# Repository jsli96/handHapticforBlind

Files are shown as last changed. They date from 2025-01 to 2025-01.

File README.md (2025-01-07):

# Hand Haptic for Blind Users in VR
This repo is for paper "Comparing Vibrotactile and Skin-Stretch Haptic Feedback for Conveying
Spatial Information of Virtual Objects to Blind VR Users"

The repo includes the list of hardware (3D model), control interface, Arduion code for motors, and calibration & test applications.

The image of testing device

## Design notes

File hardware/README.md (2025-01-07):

# Hardware componment list

1. linear rail with motor:
	- x axis (x1): https://a.co/d/0Zzcw9q
	- y axis (x2): https://a.co/d/i22Iq13
	- z axis (x1): https://a.co/d/0KRT372

2. T Slot Aluminum Linear Rail:
	- link: https://a.co/d/4vl8tA6
	- used for base frame and linkage 
3. Axis stand:
	- Use axis stand to connect T-slot Aluminum and two y axes linear rails.
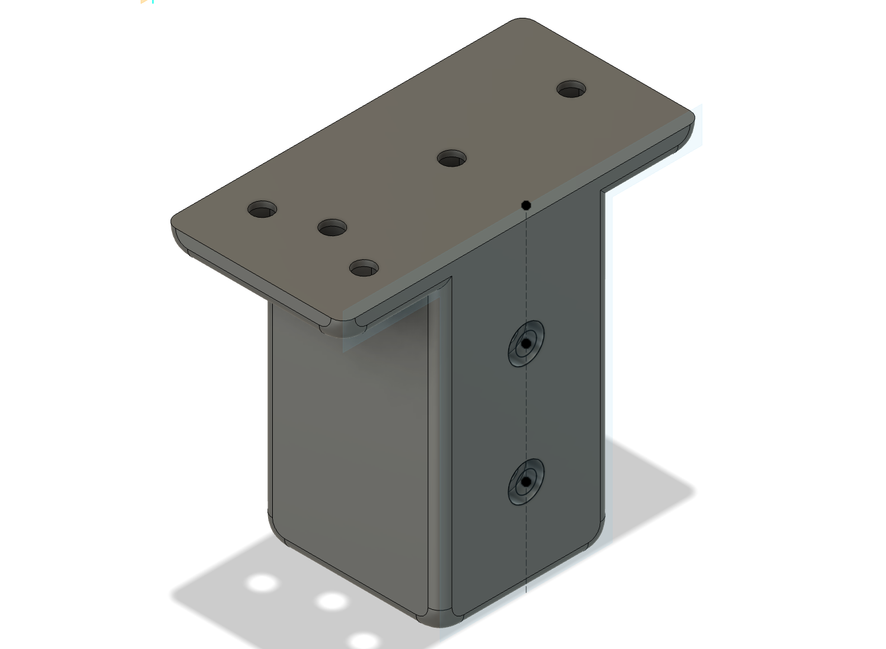
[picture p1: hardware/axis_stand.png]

4. Axis connector:
	- Use axis connector to connect x and z axis linear rail.
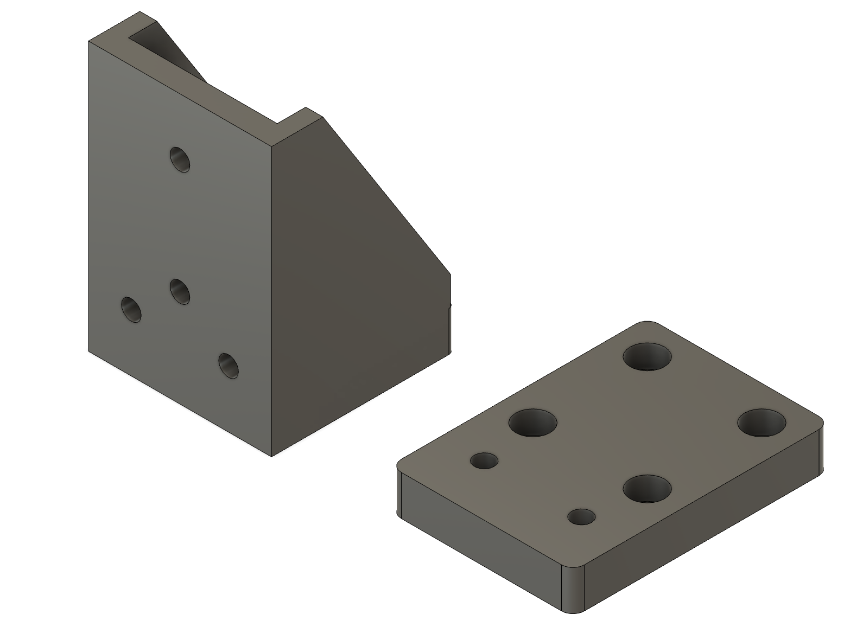
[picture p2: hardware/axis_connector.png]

5. Z probe linkage:
	- Attach Z probe linkage on the axis connector:
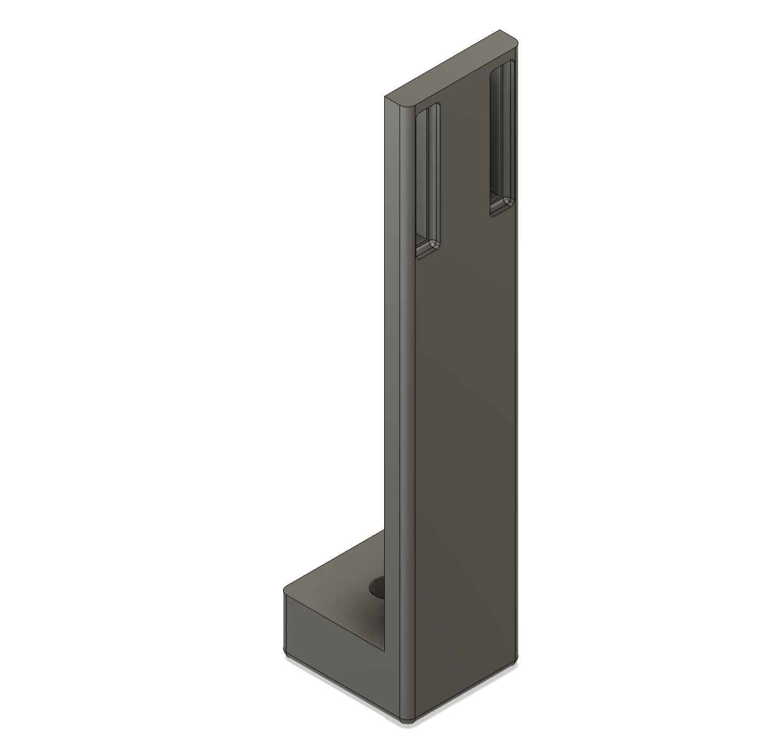
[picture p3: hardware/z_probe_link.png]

6. hand support:
	- Printed out one of these to rest users hand during the test.
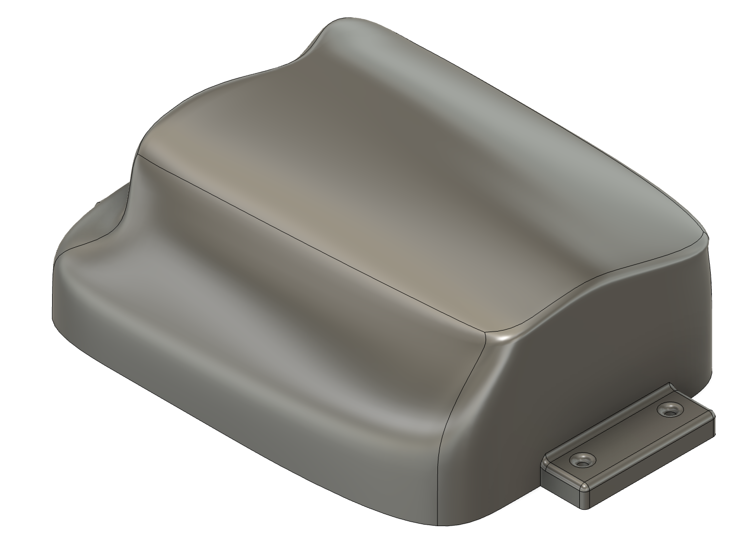
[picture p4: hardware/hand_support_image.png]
The image of testing device


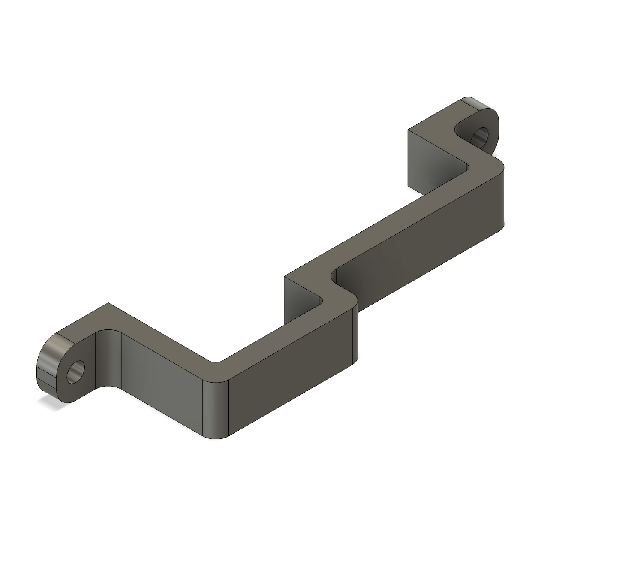
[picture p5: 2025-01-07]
hardware/camera_mount.png

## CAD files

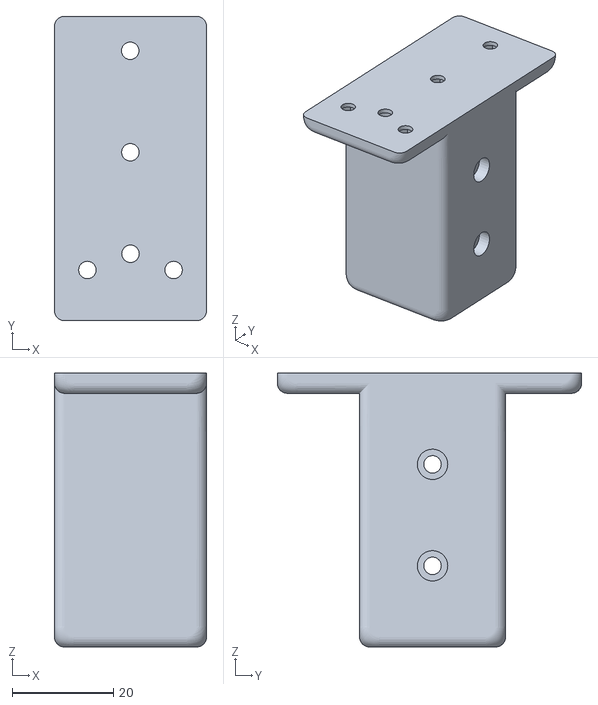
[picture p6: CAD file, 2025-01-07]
hardware/axis_stand.stl
30.0 x 60.0 x 54.0

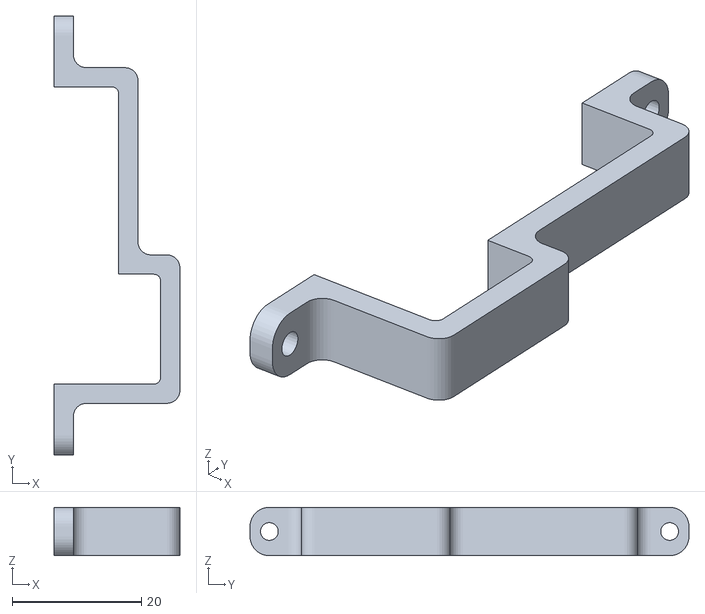
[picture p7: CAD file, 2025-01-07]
hardware/camera_mount.stl
19.5 x 68.0 x 7.50

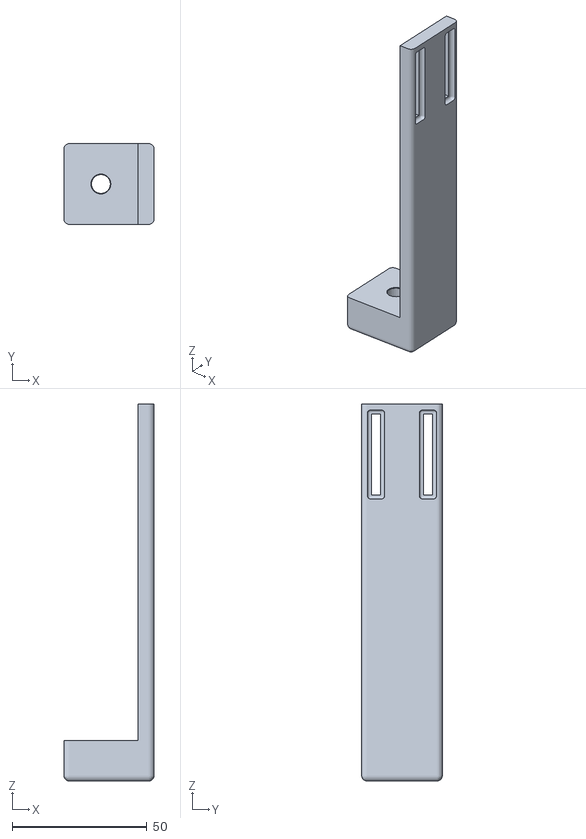
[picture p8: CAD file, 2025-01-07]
hardware/z_probe_link.stl
33.5 x 30.0 x 140.0

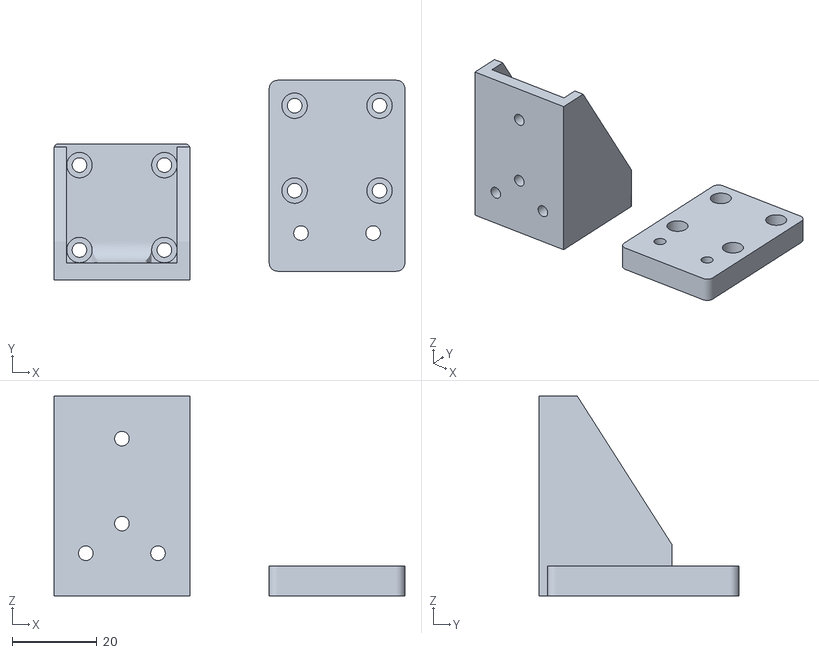
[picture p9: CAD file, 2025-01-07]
hardware/axis_connector.stl
82.7 x 47.0 x 47.0

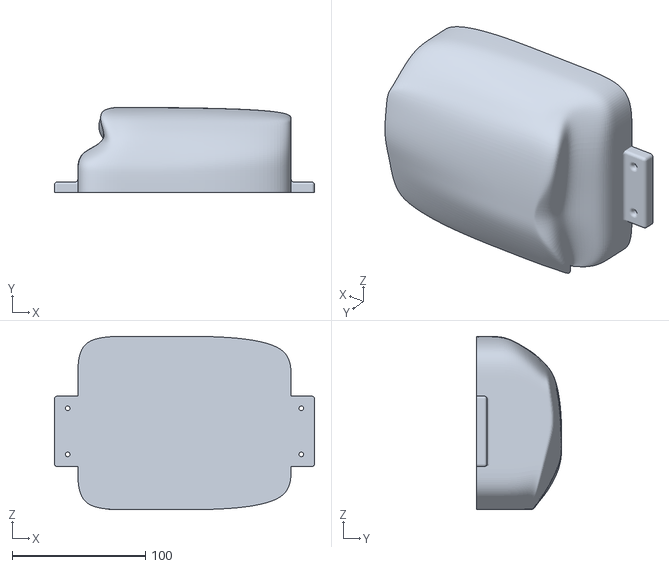
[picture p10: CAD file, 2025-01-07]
hardware/hand support.stl
194.9 x 64.0 x 130.0

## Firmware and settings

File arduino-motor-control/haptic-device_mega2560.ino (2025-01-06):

#include <TimerOne.h>
#include <AccelStepper.h>
#include <elapsedMillis.h>
#define y_Enable 56
#define y_Step 60
#define y_Dir 61
#define y_Stop 3
#define x_Enable 38
#define x_Step 54
#define x_Dir 55
#define x_Stop 2
#define z_Enable 62
#define z_Step 46
#define z_Dir 48
#define z_Stop 19
#define vib_motor_1 16

bool x_home = false;
bool y_home = false;
bool z_home = false;
const long x_center_point = -12000;
const long y_center_point = -12000;
const long z_center_point = -1000;
const int full_distance = 5000;
const int half_distance = 2250;
const int full_distance_at_45 = 3535;
const int half_distance_at_45 = 1590;
long adj_x_center = -12000;
long adj_y_center = -12000;
long adj_z_center = -1000;
long adj_z_center_low = -1000;
long adj_z_left_low = -1000;
long adj_z_right_low = -1000;
long adj_z_front_low = -1000;
long adj_z_back_low = -1000;
long z_center_move_distance = 0;
long z_left_move_distance = 0;
long z_right_move_distance = 0;
long z_front_move_distance = 0;
long z_back_move_distance = 0;
boolean z_calibration = false;
boolean vib_mode = false;
boolean stretch_mode = false;
String incomingString = "0";

AccelStepper myStepper_x(AccelStepper::DRIVER, x_Step, x_Dir, true);
AccelStepper myStepper_y(AccelStepper::DRIVER, y_Step, y_Dir, true);
AccelStepper myStepper_z(AccelStepper::DRIVER, z_Step, z_Dir, true);
elapsedMillis printTime;

void pin_init()
{
  pinMode(y_Enable, OUTPUT);
  digitalWrite(y_Enable, LOW); // the motor enable pin needs to be LOW to make driver works
  pinMode(x_Enable, OUTPUT);
  digitalWrite(x_Enable, LOW); // the motor enable pin needs to be LOW to make driver works
  pinMode(z_Enable, OUTPUT);
  digitalWrite(z_Enable, LOW); // the motor enable pin needs to be LOW to make driver works
  pinMode(x_Stop, INPUT_PULLUP);
  attachInterrupt(digitalPinToInterrupt(x_Stop), x_intr, FALLING); // Stop pin interrupt
  pinMode(y_Stop, INPUT_PULLUP);
  attachInterrupt(digitalPinToInterrupt(y_Stop), y_intr, FALLING); // Stop pin interrupt
  pinMode(z_Stop, INPUT_PULLUP);
  attachInterrupt(digitalPinToInterrupt(z_Stop), z_intr, FALLING); // Stop pin interrupt
  pinMode(vib_motor_1, OUTPUT);
  digitalWrite(vib_motor_1, LOW);
  // Initial the motor and return to the zero.
  initial_to_zero(); // Find the zero position.
}

void x_intr()
{
  static unsigned long last_interrupt_time = 0;
  unsigned long interrupt_time = millis();
  if (interrupt_time - last_interrupt_time > 900)
  {
    myStepper_x.setSpeed(0);
    x_home = true;
    Serial.println("X Motor speed set to zero.");
  }
  last_interrupt_time = interrupt_time;
}

void y_intr()
{
  static unsigned long last_interrupt_time = 0;
  unsigned long interrupt_time = millis();
  if (interrupt_time - last_interrupt_time > 900)
  {
    myStepper_y.setSpeed(0);
    y_home = true;
    Serial.println("Y Motor speed set to zero.");
  }
  last_interrupt_time = interrupt_time;
}

void z_intr()
{
  static unsigned long last_interrupt_time = 0;
  unsigned long interrupt_time = millis();
  if (interrupt_time - last_interrupt_time > 600)
  {
    myStepper_z.setSpeed(0);
    z_home = true;
    Serial.println("Z Motor speed set to zero.");
  }
  last_interrupt_time = interrupt_time;
}

void setup()
{
  Serial.begin(115200);
  myStepper_x.setMaxSpeed(1500.0); // the motor accelerates to this speed exactly without overshoot.
  myStepper_y.setMaxSpeed(1500.0); // the motor accelerates to this speed exactly without overshoot.
  myStepper_z.setMaxSpeed(1500.0); // the motor accelerates to this speed exactly without overshoot.
  myStepper_x.setAcceleration(100);
  myStepper_y.setAcceleration(100);
  myStepper_z.setAcceleration(100);
  pin_init(); // Initial the pin output functionalities.
  delay(1000);
  Serial.println("Begin moving to the center point.");
  move_to_center(x_center_point, y_center_point, z_center_point); // Move to the pre-set center point.
  detachInterrupt(digitalPinToInterrupt(x_Stop));
  detachInterrupt(digitalPinToInterrupt(y_Stop));
  detachInterrupt(digitalPinToInterrupt(z_Stop));
  Serial.println("System ready!!!");
}

void loop()
{
  if (Serial.available())
  {
    incomingString = Serial.readString();
    if (incomingString == "stop motors")
    {
      digitalWrite(y_Enable, HIGH);
      digitalWrite(x_Enable, HIGH);
      digitalWrite(z_Enable, HIGH);
      Serial.println("All motors are shutted down!");
    }
    else if (incomingString == "start motors")
    {
      digitalWrite(y_Enable, LOW);
      digitalWrite(x_Enable, LOW);
      digitalWrite(z_Enable, LOW);
      Serial.println("Motors started!");
    }
    else if (incomingString == "log xyz")
    {
      log_adjust_center_point();
    }
    else if (incomingString == "log center z lowest point")
    {
      log_center_z_lowest_point();
    }
    else if (incomingString == "log left z lowest point")
    {
      log_left_z_lowest_point();
    }
    else if (incomingString == "log right z lowest point")
    {
      log_right_z_lowest_point();
    }
    else if (incomingString == "log front z lowest point")
    {
      log_front_z_lowest_point();
    }
    else if (incomingString == "log back z lowest point")
    {
      log_back_z_lowest_point();
    }
    else if (incomingString == "pre-set home")
    {
      move_to_center(x_center_point, y_center_point, z_center_point);
    }
    else if (incomingString == "adjusted home")
    {
      move_to_center(adj_x_center, adj_y_center, adj_z_center);
    }
    else if (incomingString == "show current location")
    {
      show_current_location();
    }
    else if (incomingString[0] == 'x' || incomingString[0] == 'y' || incomingString[0] == 'z')
    {
      adjust_probe_position(incomingString);
    }
    else
    {
      points_select(incomingString);
    }

    Serial.println("Standby...");
  }
  delay(500);
}

void initial_to_zero()
{
  myStepper_y.setSpeed(1250); // Positive speed will move to zero point, negative point will move to oppisite direction.
  myStepper_x.setSpeed(1250);
  myStepper_z.setSpeed(1250);
  while (x_home == false || y_home == false || z_home == false)
  {
    myStepper_y.runSpeed();
    myStepper_x.runSpeed();
    myStepper_z.runSpeed();
  }
  myStepper_x.setCurrentPosition(0);
  myStepper_y.setCurrentPosition(0);
  myStepper_z.setCurrentPosition(0);
  myStepper_x.stop();
  myStepper_y.stop();
  myStepper_z.stop();
  Serial.println("Motor at zero position.");
}

void move_to_center(long x_c, long y_c, long z_c)
{
  myStepper_x.moveTo(x_c);
  myStepper_y.moveTo(y_c);
  myStepper_z.moveTo(z_c);
  while (myStepper_x.distanceToGo() != 0 || myStepper_y.distanceToGo() != 0 || myStepper_z.distanceToGo() != 0)
  {
    myStepper_x.setSpeed(cal_speed_dir(x_c, myStepper_x.currentPosition(), 1400));
    myStepper_y.setSpeed(cal_speed_dir(y_c, myStepper_y.currentPosition(), 1400));
    myStepper_z.setSpeed(cal_speed_dir(z_c, myStepper_z.currentPosition(), 1400));
    if (myStepper_x.distanceToGo() != 0)
    {
      myStepper_x.run();
    }
    if (myStepper_y.distanceToGo() != 0)
    {
      myStepper_y.run();
    }
    if (myStepper_z.distanceToGo() != 0)
    {
      myStepper_z.run();
    }
  }
  Serial.println("Probe at the center position.");
  show_current_location();
}

void show_current_location()
{
  Serial.print("Current motor poistion (x, y, z): ");
  Serial.print(myStepper_x.currentPosition());
  Serial.print(", ");
  Serial.print(myStepper_y.currentPosition());
  Serial.print(", ");
  Serial.println(myStepper_z.currentPosition());
}

void adjust_probe_position(String incomingString)
{
  switch (incomingString[0])
  {
  case 'x':
    Serial.print("Axis: ");
    Serial.println(incomingString[0]);
    Serial.print("Destination: ");
    Serial.println(incomingString.substring(2).toInt());
    move_x(incomingString.substring(2).toInt(), 1400);
    break;
  case 'y':
    Serial.print("Axis: ");
    Serial.println(incomingString[0]);
    Serial.print("Destination: ");
    Serial.println(incomingString.substring(2).toInt());
    move_y(incomingString.substring(2).toInt(), 1400);
    break;
  case 'z':
    Serial.print("Axis: ");
    Serial.println(incomingString[0]);
    Serial.print("Destination: ");
    Serial.println(incomingString.substring(2).toInt());
    move_z(incomingString.substring(2).toInt(), 1400);
    break;
  }
}

void points_select(String incomingString)
{
  Serial.println(incomingString);
  if (adj_x_center == -12000 || adj_y_center == -12000)
  {
    Serial.println("Please calbiate and log x y z postion first!");
  }
  if (z_calibration == false)
  {
    Serial.println("Please calbiate the lowest z postion first!");
  }
  if (z_calibration == true && adj_x_center != -12000 && adj_y_center != -12000)
  {
    int temp = incomingString.toInt();
    Serial.print("Incoming point: ");
    Serial.println(temp);
    switch (temp)
    {
    case 16:
      point_16();
      break;
    case 15:
      point_15();
      break;
    case 14:
      point_14();
      break;
    case 13:
      point_13();
      break;
    case 12:
      point_12();
      break;
    case 11:
      point_11();
      break;
    case 10:
      point_10();
      break;
    case 9:
      point_9();
      break;
    case 8:
      point_8();
      break;
    case 7:
      point_7();
      break;
    case 6:
      point_6();
      break;
    case 5:
      point_5();
      break;
    case 4:
      point_4();
      break;
    case 3:
      point_3();
      break;
    case 2:
      point_2();
      break;
    case 1:
      point_1();
      break;
    case 21:
      h_left();
      break;
    case 22:
      h_right();
      break;
    case 23:
      v_backward();
      break;
    case 24:
      v_forward();
      break;
    case 25:
      multi_fb();
      break;
    case 26:
      multi_incomplete_t();
      break;
    case 27:
      multi_complete_t();
      break;
    case 28:
      big_left_curve();
      break;
    case 29:
      small_right_curve();
      break;
    case 30:
      s_curve();
      break;

      //======================================================================//
    case 46:
      point_16_vib();
      break;
    case 45:
      point_15_vib();
      break;
    case 44:
      point_14_vib();
      break;
    case 43:
      point_13_vib();
      break;
    case 42:
      point_12_vib();
      break;
    case 41:
      point_11_vib();
      break;
    case 40:
      point_10_vib();
      break;
    case 39:
      point_9_vib();
      break;
    case 38:
      point_8_vib();
      break;
    case 37:
      point_7_vib();
      break;
    case 36:
      point_6_vib();
      break;
    case 35:
      point_5_vib();
      break;
    case 34:
      point_4_vib();
      break;
    case 33:
      point_3_vib();
      break;
    case 32:
      point_2_vib();
      break;
    case 31:
      point_1_vib();
      break;
    case 51:
      h_left_vib();
      break;
    case 52:
      h_right_vib();
      break;
    case 53:
      v_backward_vib();
      break;
    case 54:
      v_forward_vib();
      break;
    case 55:
      multi_fb_vib();
      break;
    case 56:
      multi_incomplete_t_vib();
      break;
    case 57:
      multi_complete_t_vib();
      break;
    case 58:
      big_left_curve_vib();
      break;
    case 59:
      small_right_curve_vib();
      break;
    case 60:
      s_curve_vib();
      break;
      //======================================================================//

    default:
      Serial.println("Commands not match!");
      break;
    }
  }
}

void log_adjust_center_point()
{
  adj_x_center = myStepper_x.currentPosition();
  adj_y_center = myStepper_y.currentPosition();
  adj_z_center = myStepper_z.currentPosition();
  Serial.println("Adjust center point logged!");
  show_current_location();
}

void log_center_z_lowest_point()
{
  adj_z_center_low = myStepper_z.currentPosition();
  z_center_move_distance = adj_z_center_low - adj_z_center;
  Serial.println("Z axis center lowest point logged!");
  Serial.print("Z axis center movement distance is ");
  Serial.println(z_center_move_distance);
  Serial.print(z_center_move_distance);
  Serial.print(',');
  Serial.print(z_left_move_distance);
  Serial.print(',');
  Serial.print(z_right_move_distance);
  Serial.print(',');
  Serial.print(z_front_move_distance);
  Serial.print(',');
  Serial.println(z_back_move_distance);

  show_current_location();
  if (z_center_move_distance == 0 || z_left_move_distance == 0 || z_right_move_distance == 0 || z_front_move_distance == 0 || z_back_move_distance == 0)
  {
    z_calibration = false;
  }
  else
  {
    z_calibration = true;
  }
}

void log_left_z_lowest_point()
{
  adj_z_left_low = myStepper_z.currentPosition();
  z_left_move_distance = adj_z_left_low - adj_z_center;
  Serial.println("Z axis left center lowest point logged!");
  Serial.print("Z axis left center movement distance is ");
  Serial.println(z_left_move_distance);
  Serial.print(z_center_move_distance);
  Serial.print(',');
  Serial.print(z_left_move_distance);
  Serial.print(',');
  Serial.print(z_right_move_distance);
  Serial.print(',');
  Serial.print(z_front_move_distance);
  Serial.print(',');
  Serial.println(z_back_move_distance);
  show_current_location();
  if (z_center_move_distance == 0 || z_left_move_distance == 0 || z_right_move_distance == 0 || z_front_move_distance == 0 || z_back_move_distance == 0)
  {
    z_calibration = false;
  }
  else
  {
    z_calibration = true;
  }
}

void log_right_z_lowest_point()
{
  adj_z_right_low = myStepper_z.currentPosition();
  z_right_move_distance = adj_z_right_low - adj_z_center;
  Serial.println("Z axis right lowest point logged!");
  Serial.print("Z axis right movement distance is ");
  Serial.println(z_right_move_distance);
  Serial.print(z_center_move_distance);
  Serial.print(',');
  Serial.print(z_left_move_distance);
  Serial.print(',');
  Serial.print(z_right_move_distance);
  Serial.print(',');
  Serial.print(z_front_move_distance);
  Serial.print(',');
  Serial.println(z_back_move_distance);
  show_current_location();
  if (z_center_move_distance == 0 || z_left_move_distance == 0 || z_right_move_distance == 0 || z_front_move_distance == 0 || z_back_move_distance == 0)
  {
    z_calibration = false;
  }
  else
  {
    z_calibration = true;
  }
}

void log_front_z_lowest_point()
{
  adj_z_front_low = myStepper_z.currentPosition();
  z_front_move_distance = adj_z_front_low - adj_z_center;
  Serial.println("Z axis front lowest point logged!");
  Serial.print("Z axis front movement distance is ");
  Serial.println(z_front_move_distance);
  Serial.print(z_center_move_distance);
  Serial.print(',');
  Serial.print(z_left_move_distance);
  Serial.print(',');
  Serial.print(z_right_move_distance);
  Serial.print(',');
  Serial.print(z_front_move_distance);
  Serial.print(',');
  Serial.println(z_back_move_distance);
  show_current_location();
  if (z_center_move_distance == 0 || z_left_move_distance == 0 || z_right_move_distance == 0 || z_front_move_distance == 0 || z_back_move_distance == 0)
  {
    z_calibration = false;
  }
  else
  {
    z_calibration = true;
  }
}

void log_back_z_lowest_point()
{
  adj_z_back_low = myStepper_z.currentPosition();
  z_back_move_distance = adj_z_back_low - adj_z_center;
  Serial.println("Z axis back lowest point logged!");
  Serial.print("Z axis back movement distance is ");
  Serial.println(z_back_move_distance);
  Serial.print(z_center_move_distance);
  Serial.print(',');
  Serial.print(z_left_move_distance);
  Serial.print(',');
  Serial.print(z_right_move_distance);
  Serial.print(',');
  Serial.print(z_front_move_distance);
  Serial.print(',');
  Serial.println(z_back_move_distance);
  show_current_location();
  if (z_center_move_distance == 0 || z_left_move_distance == 0 || z_right_move_distance == 0 || z_front_move_distance == 0 || z_back_move_distance == 0)
  {
    z_calibration = false;
  }
  else
  {
    z_calibration = true;
  }
}

long cal_speed_dir(long target_pos, long current_pos, int abs_speed)
{
  long result = target_pos - current_pos;
  if (result > 0)
  {
    return abs(abs_speed);
  }
  else
  {
    return -abs(abs_speed);
  }
}

void move_x(long distance, int speed)
{
  myStepper_x.move(distance);
  // Serial.println(distance);
  if (speed > 1500)
  {
    speed = 1500;
  }
  else if (speed < 0)
  {
    speed = 0;
  }

  while (myStepper_x.distanceToGo() != 0)
  {
    myStepper_x.setSpeed(cal_speed_dir(myStepper_x.currentPosition() + distance, myStepper_x.currentPosition(), speed));
    myStepper_x.run();
  }
  Serial.print("X current position: ");
  Serial.println(myStepper_x.currentPosition());
}

void move_y(long distance, int speed)
{
  myStepper_y.move(distance);
  // Serial.println(distance);
  if (speed > 1500)
  {
    speed = 1500;
  }
  else if (speed < 0)
  {
    speed = 0;
  }
  while (myStepper_y.distanceToGo() != 0)
  {
    myStepper_y.setSpeed(cal_speed_dir(myStepper_y.currentPosition() + distance, myStepper_y.currentPosition(), speed));
    myStepper_y.run();
  }
  Serial.print("Y current position: ");
  Serial.println(myStepper_y.currentPosition());
}

void move_z(long distance, int speed)
{
  myStepper_z.move(distance);
  // Serial.println(distance);
  if (speed > 1500)
  {
    speed = 1500;
  }
  else if (speed < 0)
  {
    speed = 0;
  }
  while (myStepper_z.distanceToGo() != 0)
  {
    myStepper_z.setSpeed(cal_speed_dir(myStepper_z.currentPosition() + distance, myStepper_z.currentPosition(), speed));
    myStepper_z.run();
  }
  Serial.print("Z current position: ");
  Serial.println(myStepper_z.currentPosition());
}

void move_x_y_parallel(long x_distance, long y_distance, int speed)
{
  myStepper_x.move(x_distance);
  myStepper_y.move(y_distance);
  if (speed > 1500)
  {
    speed = 1500;
  }
  else if (speed < 0)
  {
    speed = 0;
  }
  while (myStepper_x.distanceToGo() != 0 || myStepper_y.distanceToGo() != 0)
  {
    myStepper_x.setSpeed(cal_speed_dir(myStepper_x.currentPosition() + x_distance, myStepper_x.currentPosition(), speed));
    myStepper_y.setSpeed(cal_speed_dir(myStepper_y.currentPosition() + y_distance, myStepper_y.currentPosition(), speed));
    if (myStepper_x.distanceToGo() != 0)
    {
      myStepper_x.run();
    }
    if (myStepper_y.distanceToGo() != 0)
    {
      myStepper_y.run();
    }
  }
}

void move_x_y_z_in_task(long x_distance, long y_distance, long z_distance)
{
  double z_speed;
  myStepper_x.move(x_distance);
  myStepper_y.move(y_distance);
  myStepper_z.move(z_distance);
  if (x_distance == 0)
  {
    z_speed = abs(z_distance / (y_distance / 1400));
  }
  else
  {
    z_speed = abs(z_distance / (x_distance / 1400));
  }
  Serial.println(z_speed);
  while (myStepper_x.distanceToGo() != 0 || myStepper_y.distanceToGo() != 0)
  {
    myStepper_x.setSpeed(cal_speed_dir(myStepper_x.currentPosition() + x_distance, myStepper_x.currentPosition(), 1400));
    myStepper_y.setSpeed(cal_speed_dir(myStepper_y.currentPosition() + y_distance, myStepper_y.currentPosition(), 1400));
    myStepper_z.setSpeed(cal_speed_dir(myStepper_z.currentPosition() + z_distance, myStepper_z.currentPosition(), z_speed));

    if (myStepper_x.distanceToGo() != 0)
    {
      myStepper_x.run();
    }
    if (myStepper_y.distanceToGo() != 0)
    {
      myStepper_y.run();
    }
    if (myStepper_z.distanceToGo() != 0)
    {
      myStepper_z.run();
    }
  }
}

//=========================Skin stretch patterns=================//
void point_16()
{
  Serial.println("Now execute point 16.");
  move_to_center(adj_x_center, adj_y_center, adj_z_center);
  int z_moveDown_distance = adj_z_center_low - adj_z_center;
  delay(500);
  move_z(z_moveDown_distance, 1400);
  int z_adjustment = adj_z_front_low - adj_z_center_low;
  move_x_y_z_in_task(0, full_distance, z_adjustment);
  delay(1200);
  move_to_center(adj_x_center, adj_y_center, adj_z_center);
  Serial.println("point 16 Excuted. standby.");
}
void point_8()
{
  Serial.println("Now execute point 8.");
  move_to_center(adj_x_center, adj_y_center, adj_z_center);
  int z_moveDown_distance = adj_z_center_low - adj_z_center;
  delay(500);
  move_z(z_moveDown_distance, 1400);
  move_y(half_distance, 700);
  // int z_adjustment = adj_z_front_low - adj_z_center_low;
  // move_x_y_z_in_task(0, half_distance, z_adjustment);
  delay(1200);
  move_to_center(adj_x_center, adj_y_center, adj_z_center);
  Serial.println("point 8 Excuted. standby.");
}
void point_1()
{
  Serial.println("Now execute point 1.");
  move_to_center(adj_x_center, adj_y_center, adj_z_center);
  int z_moveDown_distance = adj_z_center_low - adj_z_center;
  delay(500);
  move_z(z_moveDown_distance, 1400);
  int z_adjustment = ((adj_z_front_low + adj_z_right_low) / 2) - adj_z_center_low;
  move_x_y_z_in_task(-full_distance_at_45, full_distance_at_45, z_adjustment);
  delay(1200);
  move_to_center(adj_x_center, adj_y_center, adj_z_center);
  Serial.println("point 1 Excuted. standby.");
}
void point_9()
{
  Serial.println("Now execute point 9.");
  move_to_center(adj_x_center, adj_y_center, adj_z_center);
  int z_moveDown_distance = adj_z_center_low - adj_z_center;
  delay(500);
  move_z(z_moveDown_distance, 1400);
  move_x_y_parallel(-half_distance_at_45, half_distance_at_45, 700);
  // int z_adjustment = ((adj_z_front_low + adj_z_right_low) / 2) - adj_z_center_low;
  // move_x_y_z_in_task(-half_distance_at_45, half_distance_at_45, z_adjustment);
  delay(1200);
  move_to_center(adj_x_center, adj_y_center, adj_z_center);
  Serial.println("point 9 Excuted. standby.");
}
void point_2()
{
  Serial.println("Now execute point 10.");
  move_to_center(adj_x_center, adj_y_center, adj_z_center);
  int z_moveDown_distance = adj_z_center_low - adj_z_center;
  delay(500);
  move_z(z_moveDown_distance, 1400);
  int z_adjustment = adj_z_right_low - adj_z_center_low;
  move_x_y_z_in_task(-full_distance, 0, z_adjustment);
  delay(1200);
  move_to_center(adj_x_center, adj_y_center, adj_z_center);
  Serial.println("point 2 Excuted. standby.");
}
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

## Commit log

2025-01-07 add hand support file
    [hand support.stl]
2025-01-07 models and images
    [axis_connector.stl, axis_stand.stl, camera_mount.stl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]
